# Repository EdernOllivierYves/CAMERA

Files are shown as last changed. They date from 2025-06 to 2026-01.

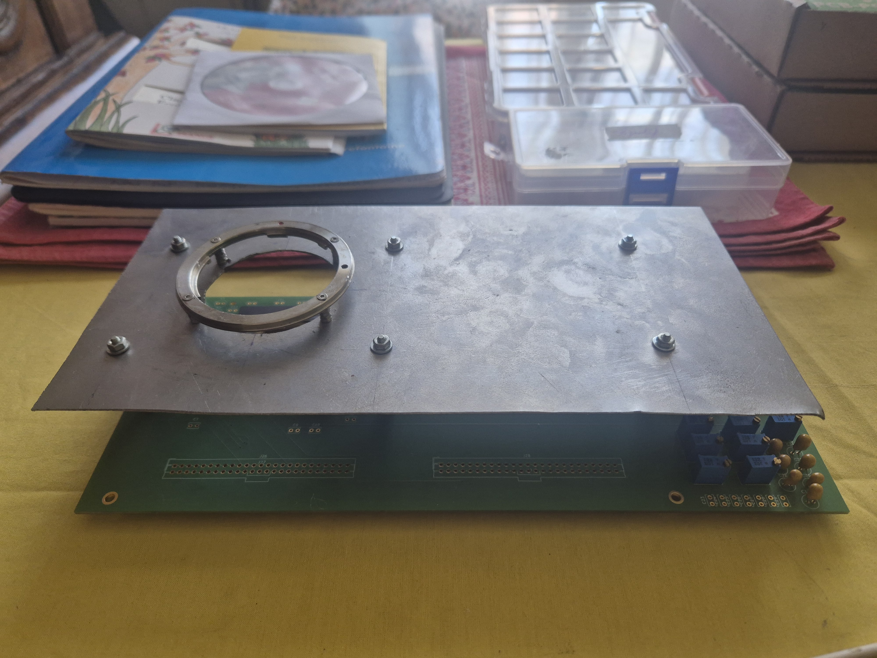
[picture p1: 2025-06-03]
20250428_150810.jpg

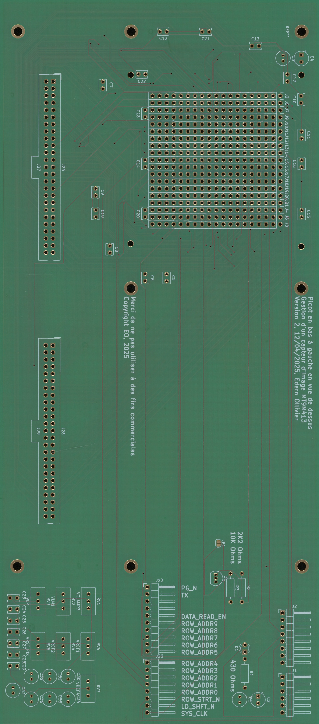
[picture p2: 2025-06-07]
BDE680a2ac0f1fb0_05.jpg

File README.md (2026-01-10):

# CAMERA
It is a perfect project for making a camera with a PCB on KiCAD 9.0.4 and a box of metal designed on QCAD 3.32.

Thank to you for using it with the driver on Windows X11 or Linux Ubuntu 24.04 LTS to see the images with the NI data acquisition board PCIe6509.

For linux you need to install Comedi and try to launch the driver :

sudo apt-get update

sudo apt-get install libcomedi-dev

sudo mknod -m 666 /dev/comedi0 c 98 0

sudo modprobe comedi comedi_num_legacy_minors=4

sudo modprobe ni_65xx

sudo comedi_config /dev/comedi0 ni_65xx

About the circuit, I want to say that the wires should be longer and better routed, with respect to the FPGA and the sensor.

Maybe an amplifier of the output signals can be added, and also an operationnal amplifier for the following voltages of the controls of the sensor can be done.

After you plug the supply, the blue LED will blink, then you must download the VHDL file of .SOF into the mother board with the QUARTUS 17.0.0.595 software.

Then you can see the signals with the scope on the Arduino connector and plug the mother board to the daugther board made of the image sensor with MT9M413.

At last the image sensor will heat a lot and you will plug the NI board on the daugther board to see the images.

PS :  Sorry but in this PCB design there is one wire which seem that has not been routed at this time, it seems to be the PG_N.

You should route the PG_N signal wire under KiCad 9.0.4 in order to make the camera to work fine.

NB :  On the PCB it seems to be wired, and also I have checked the connectivity of the wire PG_N from the Arduino connector to the image sensor with a voltmeter.

Moreover I have applied the supply on the FPGA board, with the Cyclone 10 LP Altera FPGA, and have seen the PG_N signal in yellow on my scope VOLTCRAFT DSO-2154.

BR, EO.

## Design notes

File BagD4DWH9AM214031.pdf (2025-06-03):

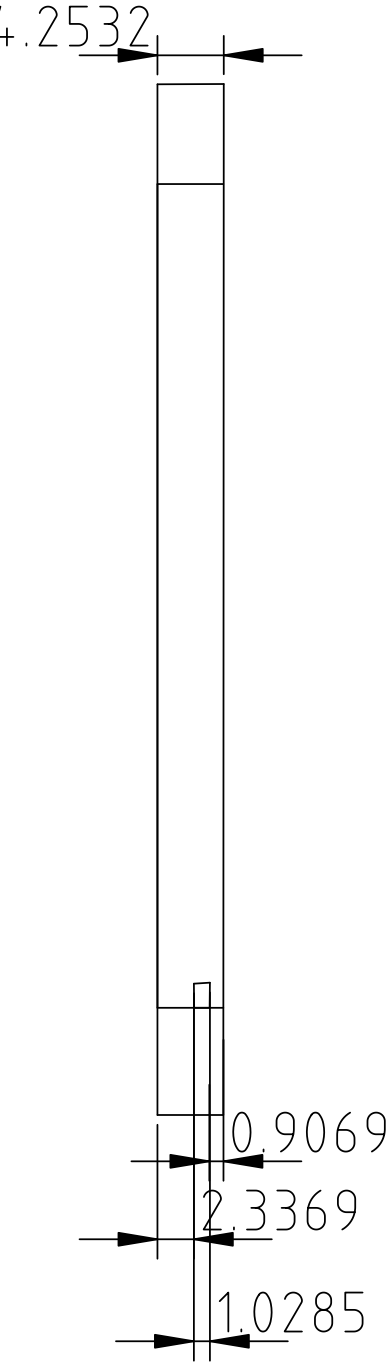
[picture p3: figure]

Imprimé avec une version d'essai de
QCAD Professional

Merci d'essayer QCAD Professional. Cette version d'essai vous permet d'essayer QCAD Professional avant de décider si vous

voulez l'acheter. Il n'est pas destiné à un usage productif. Pour commencer à utiliser QCAD Professional de façon productive, S'il vous plaît achetez une

version complète pour un prix modique auprès de notre boutique en ligne: qcad.org/shop. Avec votre achat, vous supportez le développement futur de QCAD. Merci !

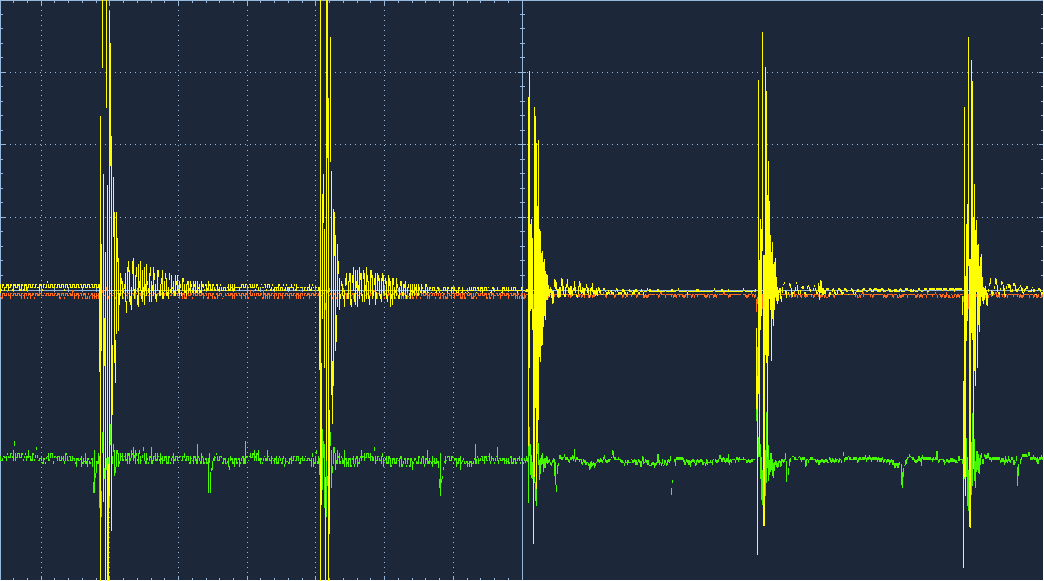
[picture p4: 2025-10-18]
PGN.gif

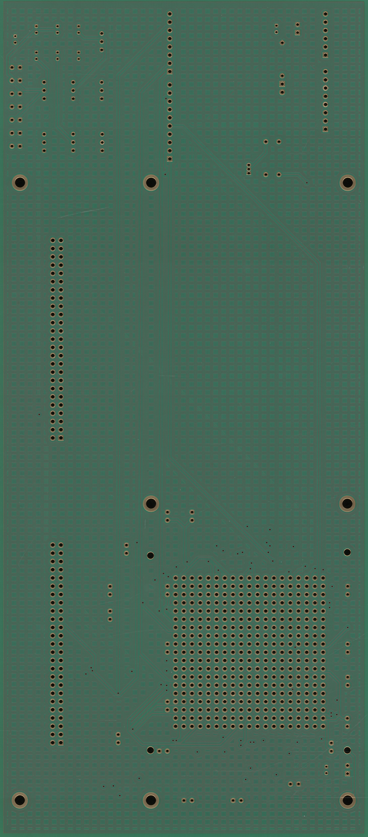
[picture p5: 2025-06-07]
BDE680a2ac0f1fb0_05_bottom.jpg

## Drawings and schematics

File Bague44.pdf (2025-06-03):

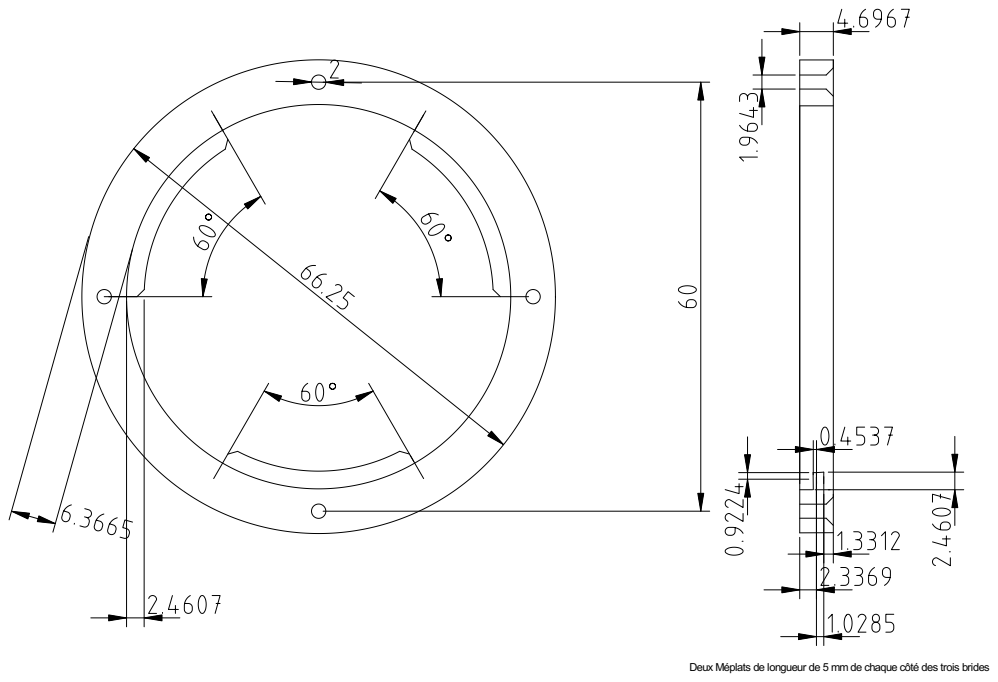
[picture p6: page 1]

Deux Méplats de longueur de 5 mm de chaque côté des trois brides

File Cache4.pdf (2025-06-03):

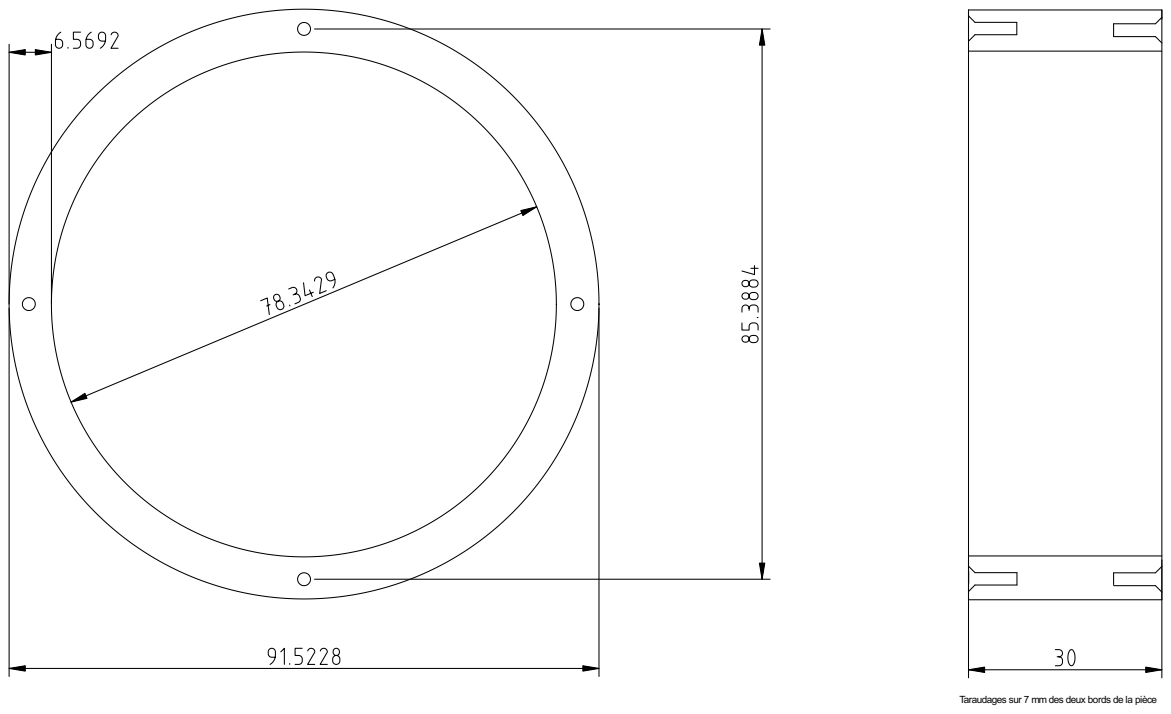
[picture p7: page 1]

Taraudages sur 7 mm des deux bords de la pièce

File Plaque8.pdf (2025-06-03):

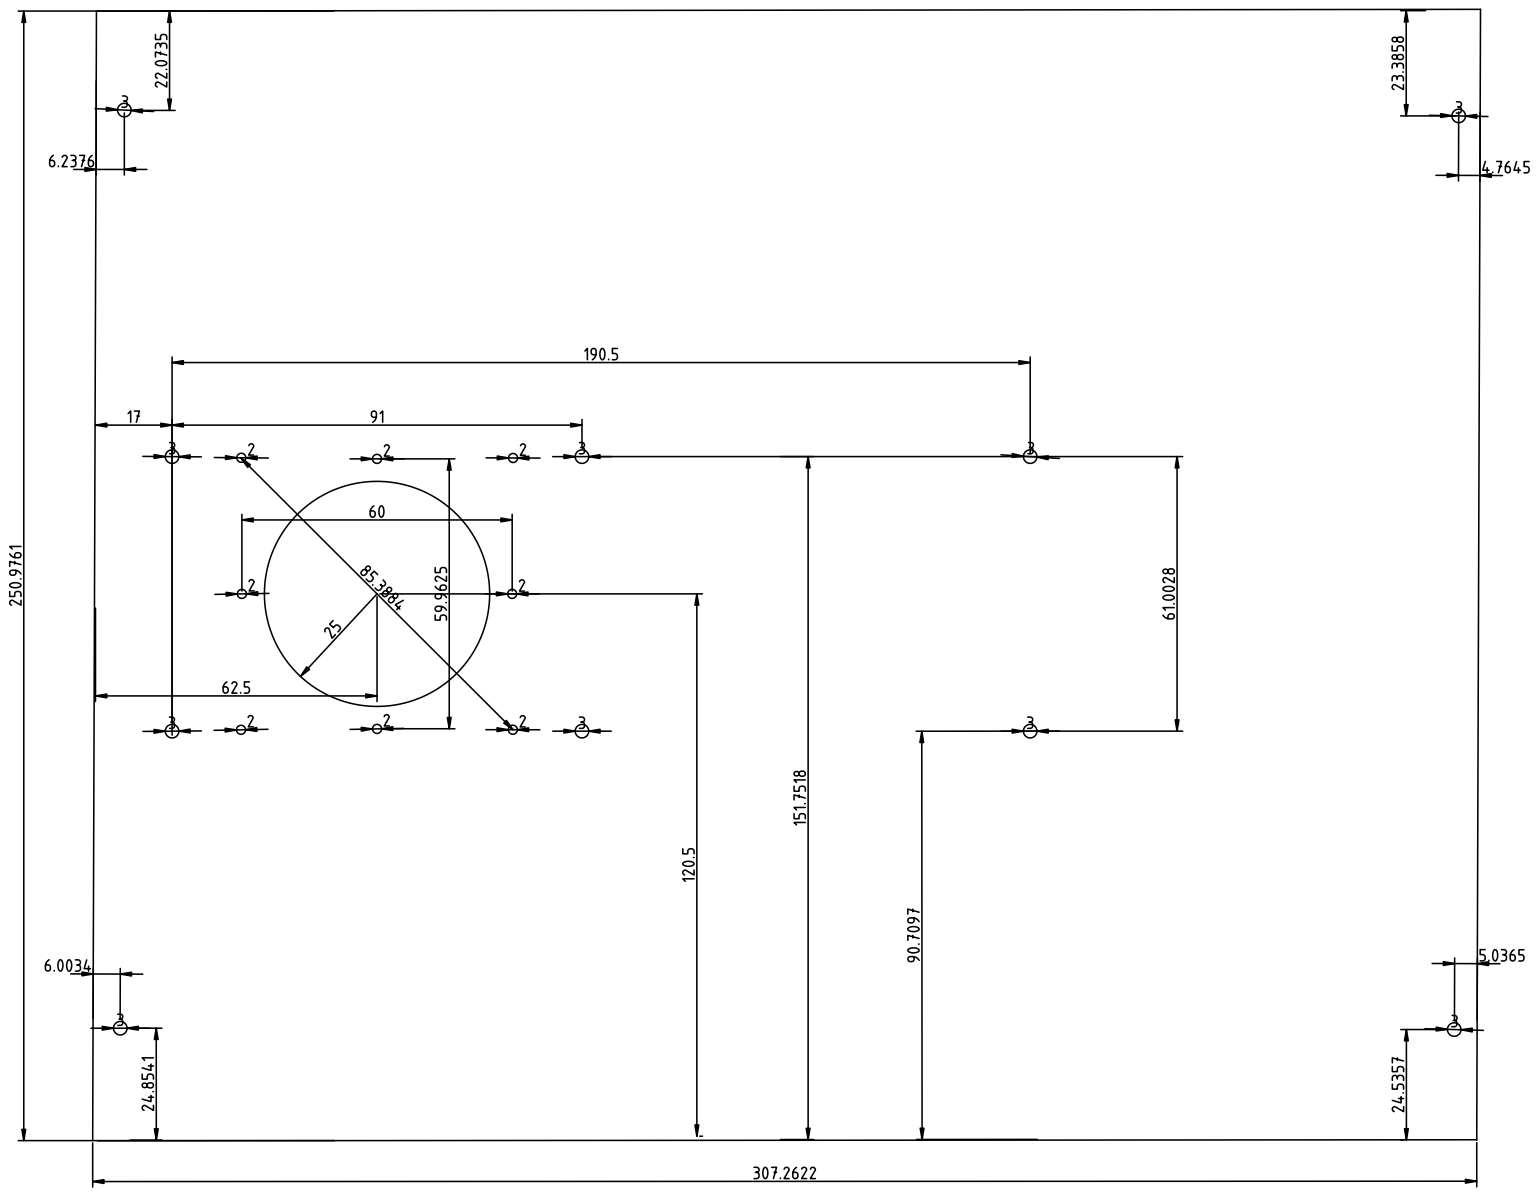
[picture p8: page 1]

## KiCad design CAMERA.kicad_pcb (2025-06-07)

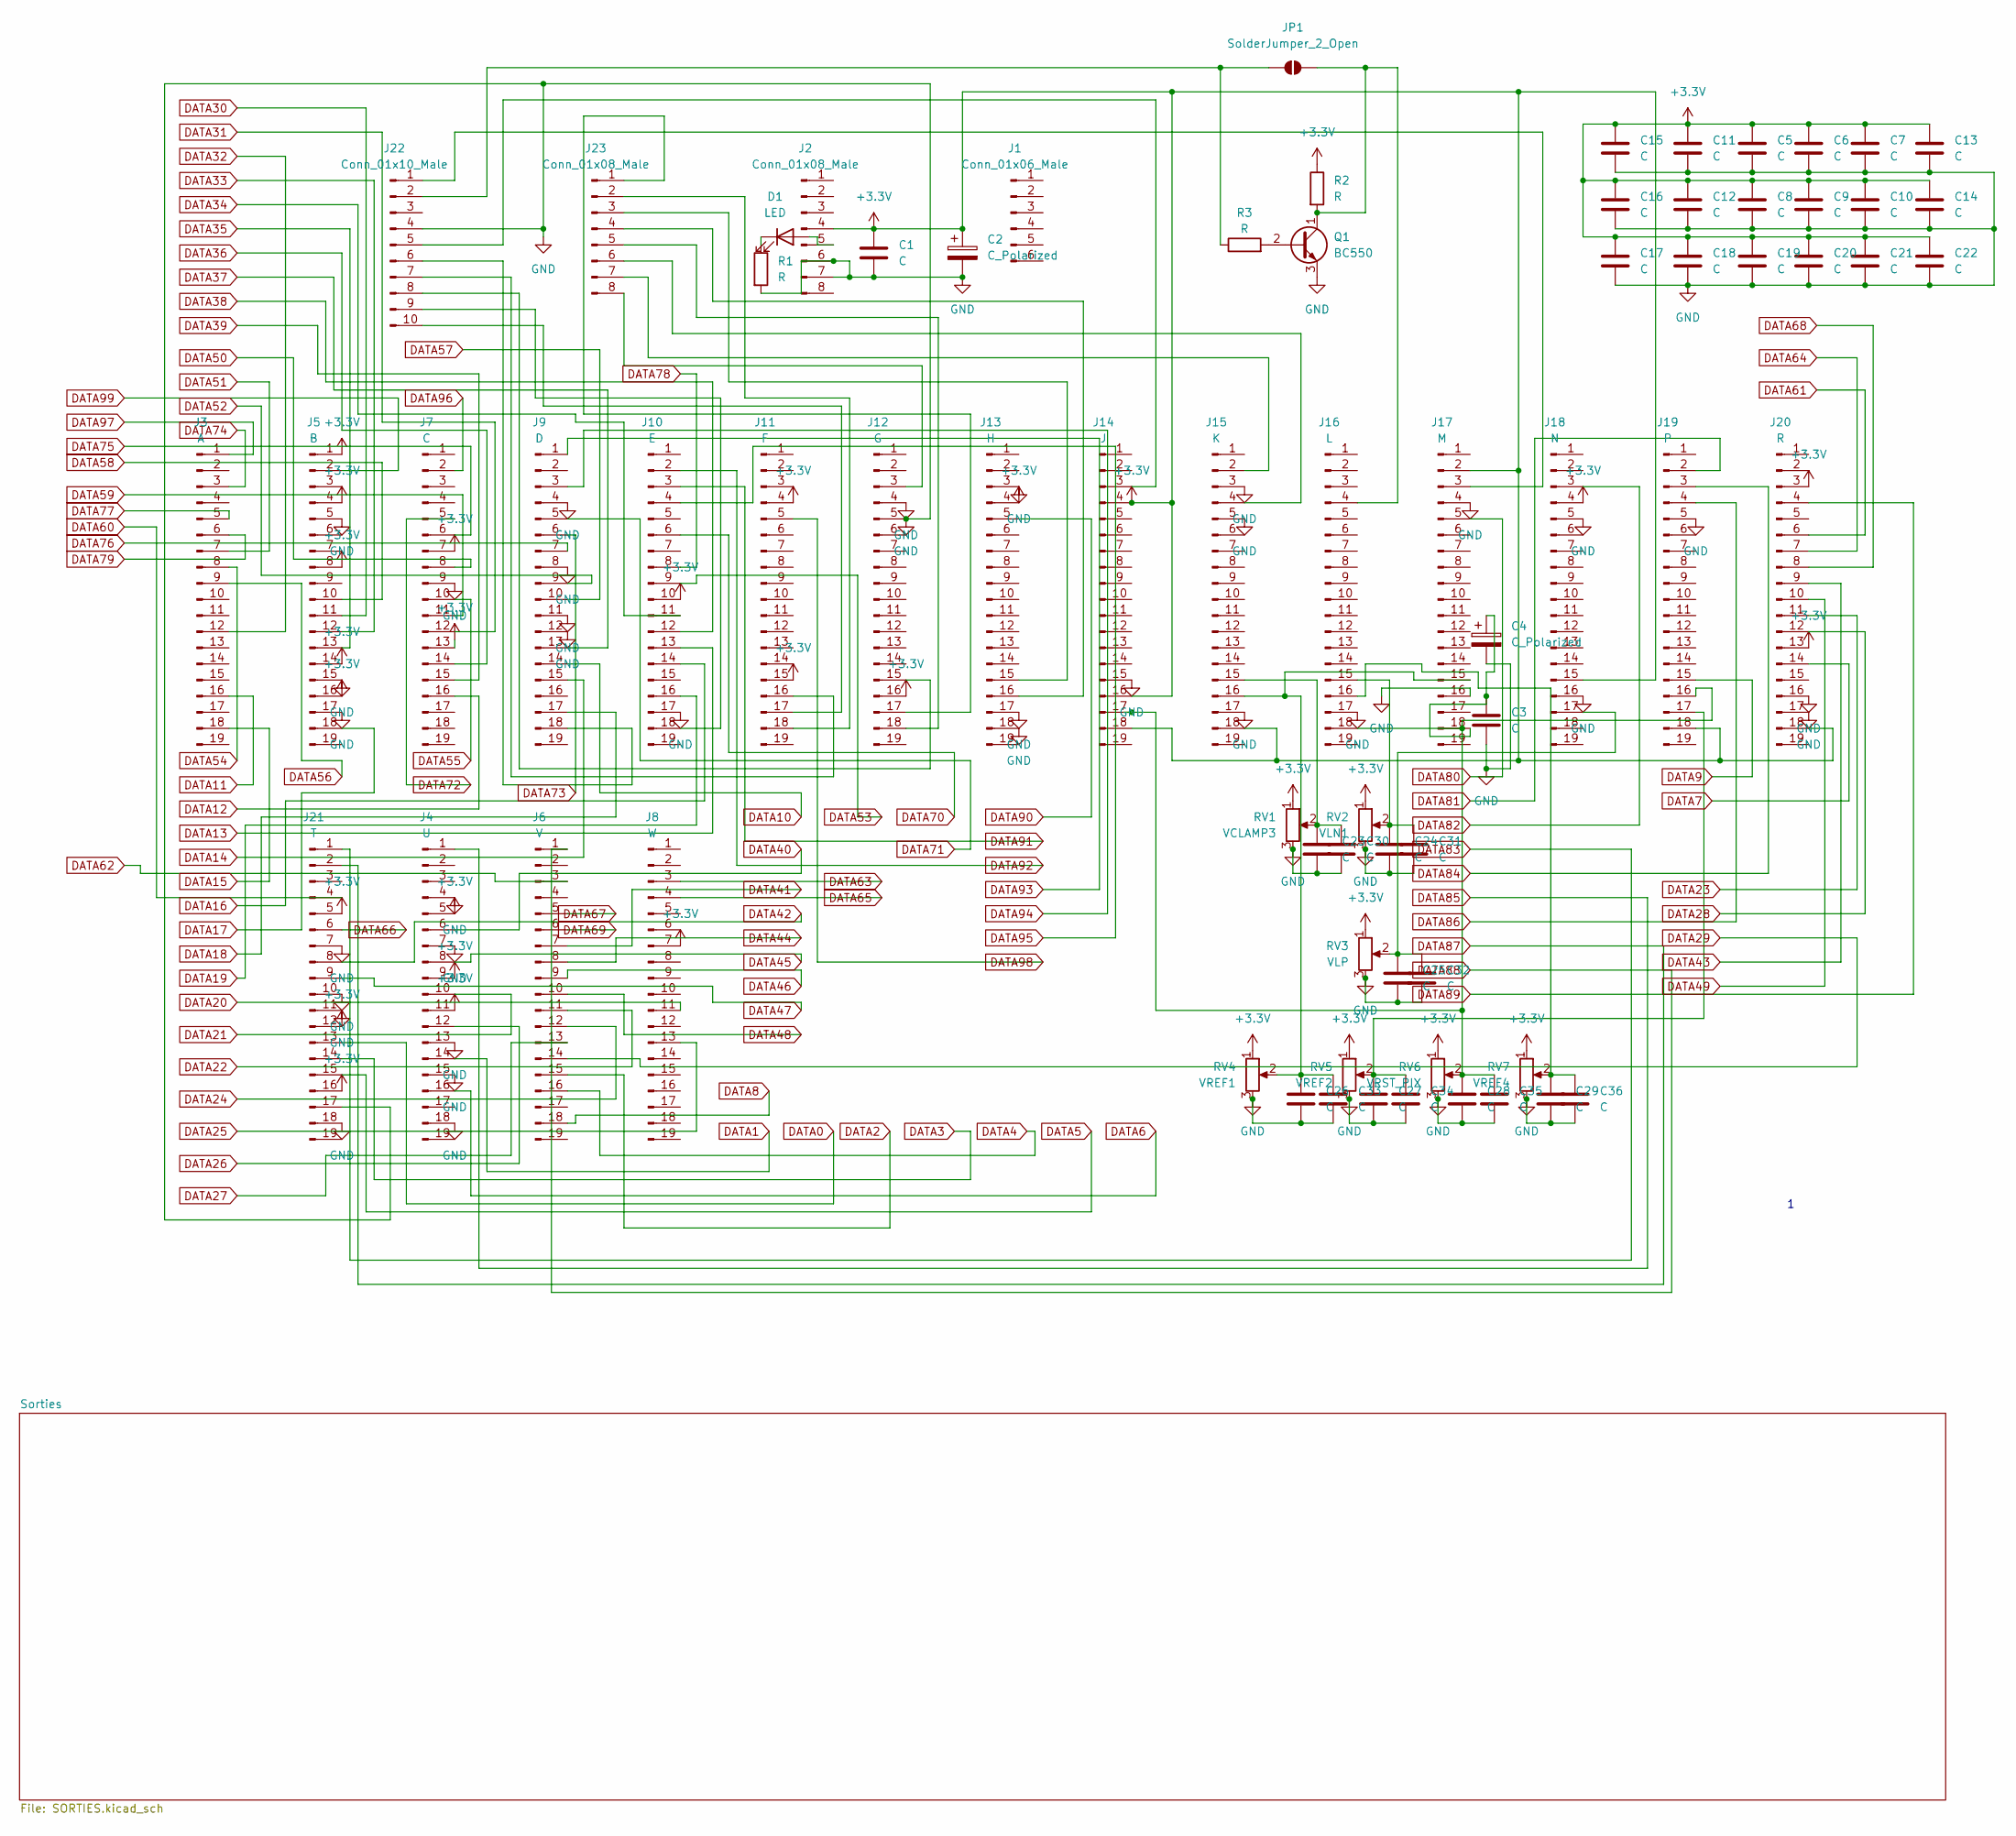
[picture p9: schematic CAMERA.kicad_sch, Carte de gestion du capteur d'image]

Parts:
C1, C3, C30, C31, C32, C33, C34, C35, C36: C; C_Radial_D5.0mm_H5.0mm_P2.00mm
C2, C4: C_Polarized; CP_Radial_Tantal_D5.0mm_P2.50mm
C5, C6, C7, C8, C9, C10, C11, C12, C13, C14, C15, C16, C17, C18, C19, C20, C21, C22, C23, C24, C25, C26, C27, C28, C29: C; C_Rect_L4.0mm_W2.5mm_P2.50mm
D1: LED; LED_D3.0mm
J1: Conn_01x06_Male; PinHeader_1x06_P2.54mm_Horizontal
J2, J23: Conn_01x08_Male; PinHeader_1x08_P2.54mm_Horizontal
J3: A; PinHeader_1x19_P2.54mm_Vertical
J4: U; PinHeader_1x19_P2.54mm_Vertical
J5: B; PinHeader_1x19_P2.54mm_Vertical
J6: V; PinHeader_1x19_P2.54mm_Vertical
J7: C; PinHeader_1x19_P2.54mm_Vertical
J8: W; PinHeader_1x19_P2.54mm_Vertical
J9: D; PinHeader_1x19_P2.54mm_Vertical
J10: E; PinHeader_1x19_P2.54mm_Vertical
J11: F; PinHeader_1x19_P2.54mm_Vertical
J12: G; PinHeader_1x19_P2.54mm_Vertical
J13: H; PinHeader_1x19_P2.54mm_Vertical
J14: J; PinHeader_1x19_P2.54mm_Vertical
J15: K; PinHeader_1x19_P2.54mm_Vertical
J16: L; PinHeader_1x19_P2.54mm_Vertical
J17: M; PinHeader_1x19_P2.54mm_Vertical
J18: N; PinHeader_1x19_P2.54mm_Vertical
J19: P; PinHeader_1x19_P2.54mm_Vertical
J20: R; PinHeader_1x19_P2.54mm_Vertical
J21: T; PinHeader_1x19_P2.54mm_Vertical
J22: Conn_01x10_Male; PinHeader_1x10_P2.54mm_Horizontal
JP1: SolderJumper_2_Open; SolderJumper-2_P1.3mm_Open_RoundedPad1.0x1.5mm
Q1: BC550; TO-92_Inline
R1, R2, R3: R; R_Axial_DIN0207_L6.3mm_D2.5mm_P10.16mm_Horizontal
RV1: VCLAMP3; Potentiometer_Bourns_3296W_Vertical
RV2: VLN1; Potentiometer_Bourns_3296W_Vertical
RV3: VLP; Potentiometer_Bourns_3296W_Vertical
RV4: VREF1; Potentiometer_Bourns_3296W_Vertical
RV5: VREF2; Potentiometer_Bourns_3296W_Vertical
RV6: VRST_PIX; Potentiometer_Bourns_3296W_Vertical
RV7: VREF4; Potentiometer_Bourns_3296W_Vertical

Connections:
+3.3V: C1.1, C2.1, C5.1, C6.1, C7.1, C8.1, C9.1, C10.1, C11.1, C12.1, C13.1, C14.1, C15.1, C16.1, C17.1, C18.1, C19.1, C20.1, C21.1, C22.1, J2.4, J4.5, J4.9, J4.11, J5.1, J5.4, J5.8, J5.14, J5.16, J7.7, J7.13, J8.7, J10.10, J11.4, J11.15, J12.16, J13.4, J14.4, J14.16, J14.18, J15.18, J17.2, J18.4, J18.15, J19.18, J20.3, J20.13, J20.18, J21.5, J21.12, J21.16, R2.1, RV1.1, RV2.1, RV3.1, RV4.1, RV5.1, RV6.1, RV7.1
DATA0: J21.13; also elsewhere on the board
DATA1: J4.14; also elsewhere on the board
DATA2: J6.15; also elsewhere on the board
DATA3: J21.14; also elsewhere on the board
DATA4: J6.16; also elsewhere on the board
DATA5: J21.15; also elsewhere on the board
DATA6: J4.16; also elsewhere on the board
DATA7: J20.14; also elsewhere on the board
DATA8: J6.18; also elsewhere on the board
DATA9: J19.15; also elsewhere on the board
DATA10: J9.14; also elsewhere on the board
DATA11: J3.16; also elsewhere on the board
DATA12: J7.16; also elsewhere on the board
DATA13: J10.13; also elsewhere on the board
DATA14: J9.15; also elsewhere on the board
DATA15: J3.18; also elsewhere on the board
DATA16: J10.14; also elsewhere on the board
DATA17: J5.18; also elsewhere on the board
DATA18: J9.17; also elsewhere on the board
DATA19: J10.16; also elsewhere on the board
DATA20: J8.11; also elsewhere on the board
DATA21: J4.10; also elsewhere on the board
DATA22: J6.11; also elsewhere on the board
DATA23: J20.11; also elsewhere on the board
DATA24: J6.12; also elsewhere on the board
DATA25: J8.13; also elsewhere on the board
DATA26: J4.12; also elsewhere on the board
DATA27: J6.13; also elsewhere on the board
DATA28: J20.12; also elsewhere on the board
DATA29: J6.14; also elsewhere on the board
DATA30: J5.11; also elsewhere on the board
DATA31: J7.12; also elsewhere on the board
DATA32: J3.12; also elsewhere on the board
DATA33: J5.12; also elsewhere on the board
DATA34: J10.11; also elsewhere on the board
DATA35: J5.13; also elsewhere on the board
DATA36: J7.14; also elsewhere on the board
DATA37: J9.13; also elsewhere on the board
DATA38: J10.12; also elsewhere on the board
DATA39: J7.15; also elsewhere on the board
DATA40: J4.6; also elsewhere on the board
DATA41: J6.7; also elsewhere on the board
DATA42: J21.8; also elsewhere on the board
DATA43: J20.9; also elsewhere on the board
DATA44: J6.8; also elsewhere on the board
DATA45: J4.8; also elsewhere on the board
DATA46: J6.9; also elsewhere on the board
DATA47: J21.9; also elsewhere on the board
DATA48: J6.10; also elsewhere on the board
DATA49: J20.10; also elsewhere on the board
DATA50: J7.8; also elsewhere on the board
DATA51: J3.7; also elsewhere on the board
DATA52: J9.9; also elsewhere on the board
DATA53: J10.9; also elsewhere on the board
DATA54: J3.8; also elsewhere on the board
DATA55: J7.10; also elsewhere on the board
DATA56: J3.9; also elsewhere on the board
DATA57: J9.10; also elsewhere on the board
DATA58: J5.10; also elsewhere on the board
DATA59: J7.11; also elsewhere on the board
DATA60: J21.4; also elsewhere on the board
DATA61: J20.6; also elsewhere on the board
DATA62: J6.3; also elsewhere on the board
DATA63: J8.3; also elsewhere on the board
DATA64: J20.7; also elsewhere on the board
DATA65: J8.4; also elsewhere on the board
DATA66: J21.6; also elsewhere on the board
DATA67: J6.5; also elsewhere on the board
DATA68: J20.8; also elsewhere on the board
DATA69: J6.6; also elsewhere on the board
DATA70: J10.6; also elsewhere on the board
DATA71: J9.5; also elsewhere on the board
DATA72: J7.5; also elsewhere on the board
DATA73: J9.6; also elsewhere on the board
DATA74: J3.3; also elsewhere on the board
DATA75: J7.6; also elsewhere on the board
DATA76: J9.7; also elsewhere on the board
DATA77: J3.5; also elsewhere on the board
DATA78: J10.8; also elsewhere on the board
DATA79: J3.6; also elsewhere on the board
DATA80: J17.5; also elsewhere on the board
DATA81: J19.2; also elsewhere on the board
DATA82: J18.3; also elsewhere on the board
DATA83: J21.1; also elsewhere on the board
DATA84: J19.3; also elsewhere on the board
DATA85: J4.1; also elsewhere on the board
DATA86: J19.4; also elsewhere on the board
DATA87: J21.2; also elsewhere on the board
DATA88: J6.1; also elsewhere on the board
DATA89: J20.4; also elsewhere on the board
DATA90: J13.5; also elsewhere on the board
DATA91: J10.3; also elsewhere on the board
DATA92: J10.2; also elsewhere on the board
DATA93: J9.1; also elsewhere on the board
DATA94: J9.3; also elsewhere on the board
DATA95: J10.4; also elsewhere on the board
DATA96: J7.2; also elsewhere on the board
DATA97: J3.1; also elsewhere on the board
DATA98: J11.5; also elsewhere on the board
DATA99: J5.2; also elsewhere on the board
GND: C1.2, C2.2, C3.2, C4.2, C5.2, C6.2, C7.2, C8.2, C9.2, C10.2, C11.2, C12.2, C13.2, C14.2, C15.2, C16.2, C17.2, C18.2, C19.2, C20.2, C21.2, C22.2, C23.2, C24.2, C25.2, C26.2, C27.2, C28.2, C29.2, C30.2, C31.2, C32.2, C33.2, C34.2, C35.2, C36.2, J2.6, J2.7, J4.4, J4.7, J4.13, J4.15, J4.18, J5.5, J5.15, J5.17, J7.9, J9.4, J9.8, J9.11, J9.12, J10.17, J12.4, J12.5, J13.3, J13.17, J13.18, J14.15, J15.3, J15.5, J15.17, J16.17, J17.4, J17.16, J18.5, J18.16, J19.5, J20.16, J20.17, J21.7, J21.10, J21.11, J21.17, J21.18, J22.4, Q1.3 (E), R1.2, RV1.3, RV2.3, RV3.3, RV4.3, RV5.3, RV6.3, RV7.3
unnamed: D1.2 (A), J2.5
unnamed: D1.1 (K), R1.1
unnamed: J10.18, J22.9
unnamed: J11.16, J22.7
unnamed: J11.17, J22.10
unnamed: J11.18, J23.2
unnamed: J12.3, J23.8
unnamed: J12.15, J22.8
unnamed: J12.17, J23.1
unnamed: J12.18, J23.5
unnamed: J13.15, J23.3
unnamed: J13.16, J23.4
unnamed: J14.3, J22.5
unnamed: C28.1, C35.1, J14.17, J16.18, J19.16, RV6.2
unnamed: J15.2, J23.7
unnamed: J15.4, J23.6
unnamed: C23.1, C30.1, J15.15, RV1.2
unnamed: C26.1, C33.1, J15.16, J17.15, RV4.2
unnamed: J16.4, JP1.1 (A), Q1.1 (C), R2.2
unnamed: C24.1, C31.1, J16.15, RV2.2
unnamed: C29.1, C36.1, J16.16, RV7.2
unnamed: J17.3, J22.1
unnamed: C3.1, C4.1, J17.18
unnamed: C25.1, C32.1, J18.17, RV3.2
unnamed: C27.1, C34.1, J19.17, RV5.2
unnamed: J22.2, JP1.2 (B), R3.1
unnamed: J9.18, J22.6
unnamed: Q1.2 (B), R3.2

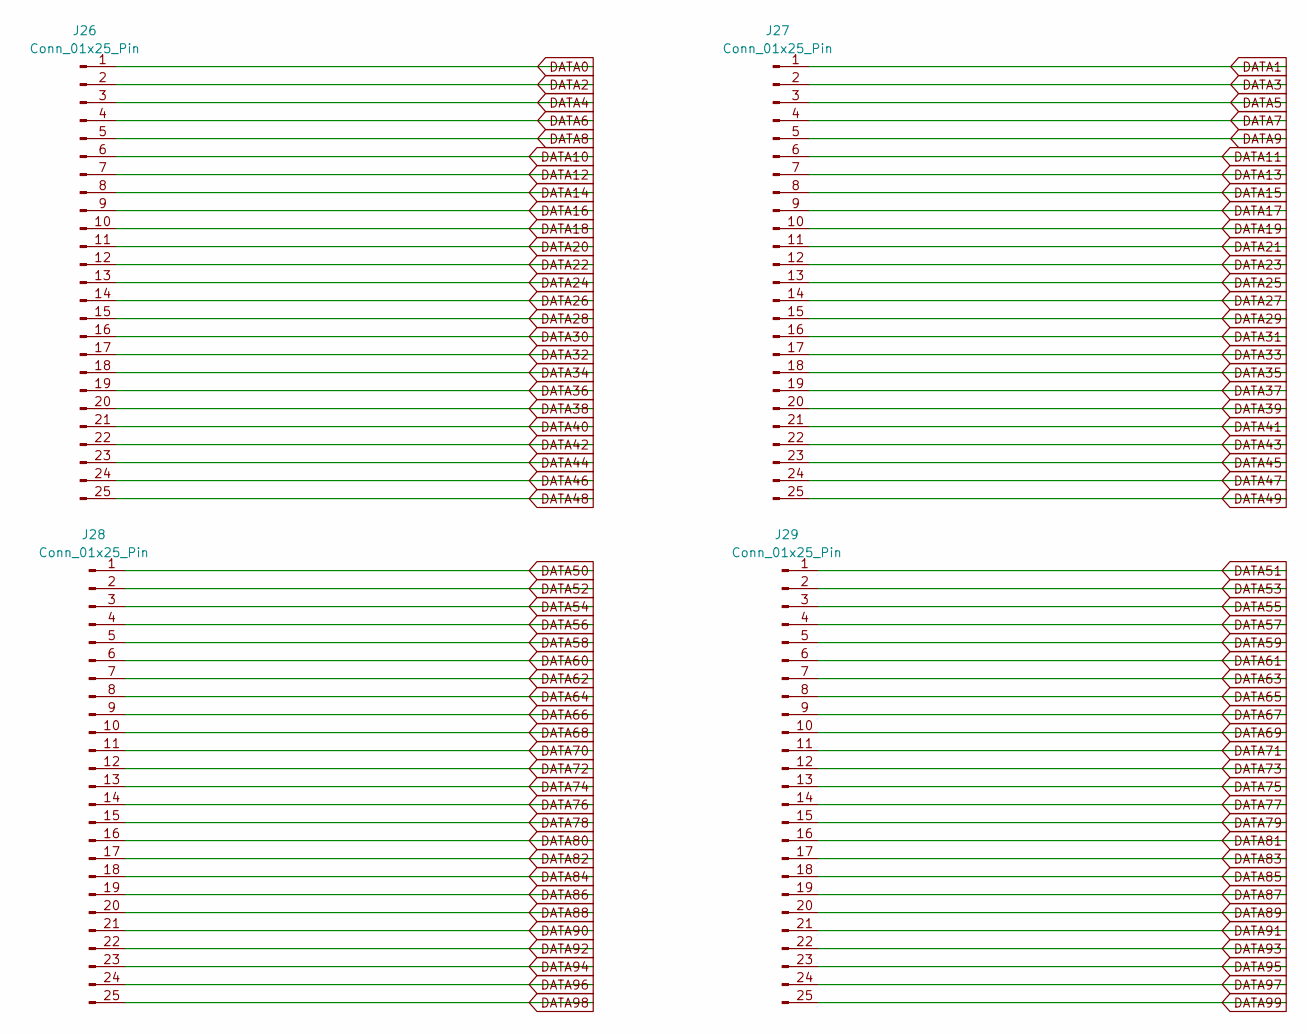
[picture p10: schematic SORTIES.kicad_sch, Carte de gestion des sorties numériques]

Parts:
J26, J27, J28, J29: Conn_01x25_Pin; Molex_SL_171971-0025_1x25_P2.54mm_Vertical

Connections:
DATA0: J26.1; also elsewhere on the board
DATA1: J27.1; also elsewhere on the board
DATA2: J26.2; also elsewhere on the board
DATA3: J27.2; also elsewhere on the board
DATA4: J26.3; also elsewhere on the board
DATA5: J27.3; also elsewhere on the board
DATA6: J26.4; also elsewhere on the board
DATA7: J27.4; also elsewhere on the board
DATA8: J26.5; also elsewhere on the board
DATA9: J27.5; also elsewhere on the board
DATA10: J26.6; also elsewhere on the board
DATA11: J27.6; also elsewhere on the board
DATA12: J26.7; also elsewhere on the board
DATA13: J27.7; also elsewhere on the board
DATA14: J26.8; also elsewhere on the board
DATA15: J27.8; also elsewhere on the board
DATA16: J26.9; also elsewhere on the board
DATA17: J27.9; also elsewhere on the board
DATA18: J26.10; also elsewhere on the board
DATA19: J27.10; also elsewhere on the board
DATA20: J26.11; also elsewhere on the board
DATA21: J27.11; also elsewhere on the board
DATA22: J26.12; also elsewhere on the board
DATA23: J27.12; also elsewhere on the board
DATA24: J26.13; also elsewhere on the board
DATA25: J27.13; also elsewhere on the board
DATA26: J26.14; also elsewhere on the board
DATA27: J27.14; also elsewhere on the board
DATA28: J26.15; also elsewhere on the board
DATA29: J27.15; also elsewhere on the board
DATA30: J26.16; also elsewhere on the board
DATA31: J27.16; also elsewhere on the board
DATA32: J26.17; also elsewhere on the board
DATA33: J27.17; also elsewhere on the board
DATA34: J26.18; also elsewhere on the board
DATA35: J27.18; also elsewhere on the board
DATA36: J26.19; also elsewhere on the board
DATA37: J27.19; also elsewhere on the board
DATA38: J26.20; also elsewhere on the board
DATA39: J27.20; also elsewhere on the board
DATA40: J26.21; also elsewhere on the board
DATA41: J27.21; also elsewhere on the board
DATA42: J26.22; also elsewhere on the board
DATA43: J27.22; also elsewhere on the board
DATA44: J26.23; also elsewhere on the board
DATA45: J27.23; also elsewhere on the board
DATA46: J26.24; also elsewhere on the board
DATA47: J27.24; also elsewhere on the board
DATA48: J26.25; also elsewhere on the board
DATA49: J27.25; also elsewhere on the board
DATA50: J28.1; also elsewhere on the board
DATA51: J29.1; also elsewhere on the board
DATA52: J28.2; also elsewhere on the board
DATA53: J29.2; also elsewhere on the board
DATA54: J28.3; also elsewhere on the board
DATA55: J29.3; also elsewhere on the board
DATA56: J28.4; also elsewhere on the board
DATA57: J29.4; also elsewhere on the board
DATA58: J28.5; also elsewhere on the board
DATA59: J29.5; also elsewhere on the board
DATA60: J28.6; also elsewhere on the board
DATA61: J29.6; also elsewhere on the board
DATA62: J28.7; also elsewhere on the board
DATA63: J29.7; also elsewhere on the board
DATA64: J28.8; also elsewhere on the board
DATA65: J29.8; also elsewhere on the board
DATA66: J28.9; also elsewhere on the board
DATA67: J29.9; also elsewhere on the board
DATA68: J28.10; also elsewhere on the board
DATA69: J29.10; also elsewhere on the board
DATA70: J28.11; also elsewhere on the board
DATA71: J29.11; also elsewhere on the board
DATA72: J28.12; also elsewhere on the board
DATA73: J29.12; also elsewhere on the board
DATA74: J28.13; also elsewhere on the board
DATA75: J29.13; also elsewhere on the board
DATA76: J28.14; also elsewhere on the board
DATA77: J29.14; also elsewhere on the board
DATA78: J28.15; also elsewhere on the board
DATA79: J29.15; also elsewhere on the board
DATA80: J28.16; also elsewhere on the board
DATA81: J29.16; also elsewhere on the board
DATA82: J28.17; also elsewhere on the board
DATA83: J29.17; also elsewhere on the board
DATA84: J28.18; also elsewhere on the board
DATA85: J29.18; also elsewhere on the board
DATA86: J28.19; also elsewhere on the board
DATA87: J29.19; also elsewhere on the board
DATA88: J28.20; also elsewhere on the board
DATA89: J29.20; also elsewhere on the board
DATA90: J28.21; also elsewhere on the board
DATA91: J29.21; also elsewhere on the board
DATA92: J28.22; also elsewhere on the board
DATA93: J29.22; also elsewhere on the board
DATA94: J28.23; also elsewhere on the board
DATA95: J29.23; also elsewhere on the board
DATA96: J28.24; also elsewhere on the board
DATA97: J29.24; also elsewhere on the board
DATA98: J28.25; also elsewhere on the board
DATA99: J29.25; also elsewhere on the board

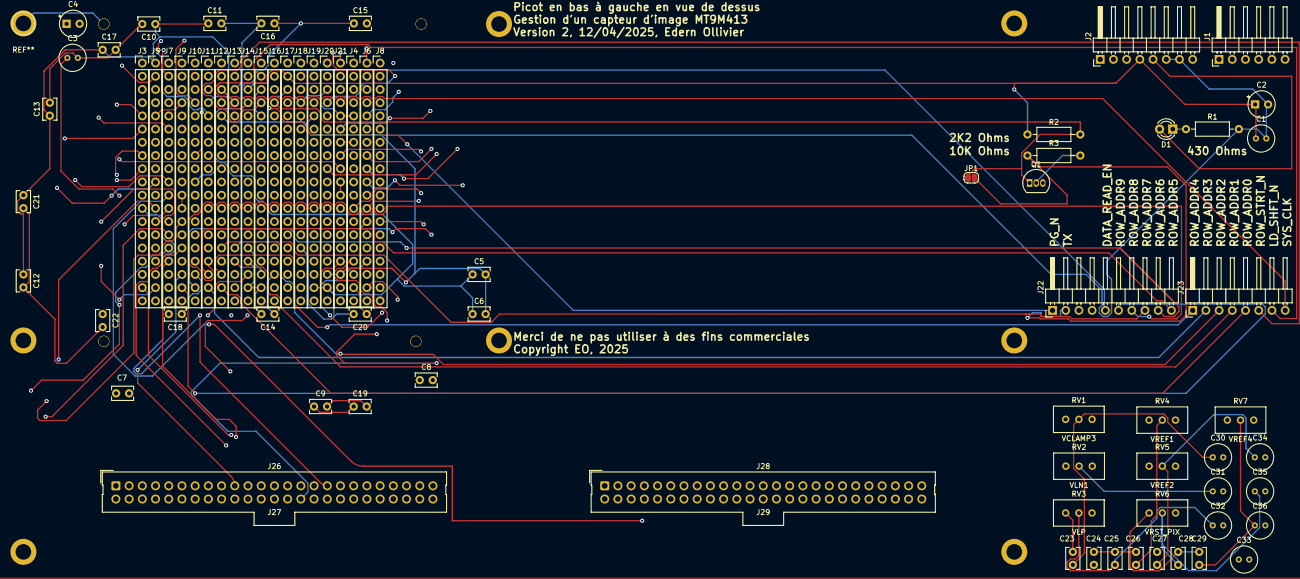
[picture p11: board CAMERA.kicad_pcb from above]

Board: 6 copper layers, 76 parts (0 on the bottom side), 130 nets.

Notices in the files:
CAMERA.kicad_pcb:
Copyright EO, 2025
